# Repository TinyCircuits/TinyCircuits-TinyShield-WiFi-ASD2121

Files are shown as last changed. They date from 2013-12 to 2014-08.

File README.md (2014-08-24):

# TinyCircuits TinyShield WiFi Board
# ASD2121 Rev2

These are the design files for the TinyCircuits ASD2121 Rev 2 PCB.  This is a TinyShield board that has a TI CC3000 WiFi module, local power supply and level shifters to connect between the TinyDuino and the WiFi Module. 

Format is in Cadsoft Eagle format - Eagle version 6.2 was used for the original design.

For more infomation on this, check out the product page at Tiny-Circuits.com:  https://tiny-circuits.com/tiny-shield-wifi.html

#License:

Design by TinyCircuits.
All design files are released under the Creative Commons Attribution Share-Alike 3.0 License, see the following link for details: http://creativecommons.org/licenses/by-sa/3.0

All text above must be included in any redistribution or derived design

This project uses designs and concepts developed as part of the Arduino project and the LilyPad project.  The TinyCircuits design files themselves (schematics, PCB and libraries) are not directly derived from these works' design files and have been created new, however the concepts and basic architecture behind the TinyDuino and TinyLily products are derived and we thank the hard work of the organizations below for their contributions to open-source hardware:
  
Original Arduino Uno Design by Team Arduino

LilyPad Arduino Design by Leah Buechley and Sparkfun Electronics

Please support the open-source hardware community

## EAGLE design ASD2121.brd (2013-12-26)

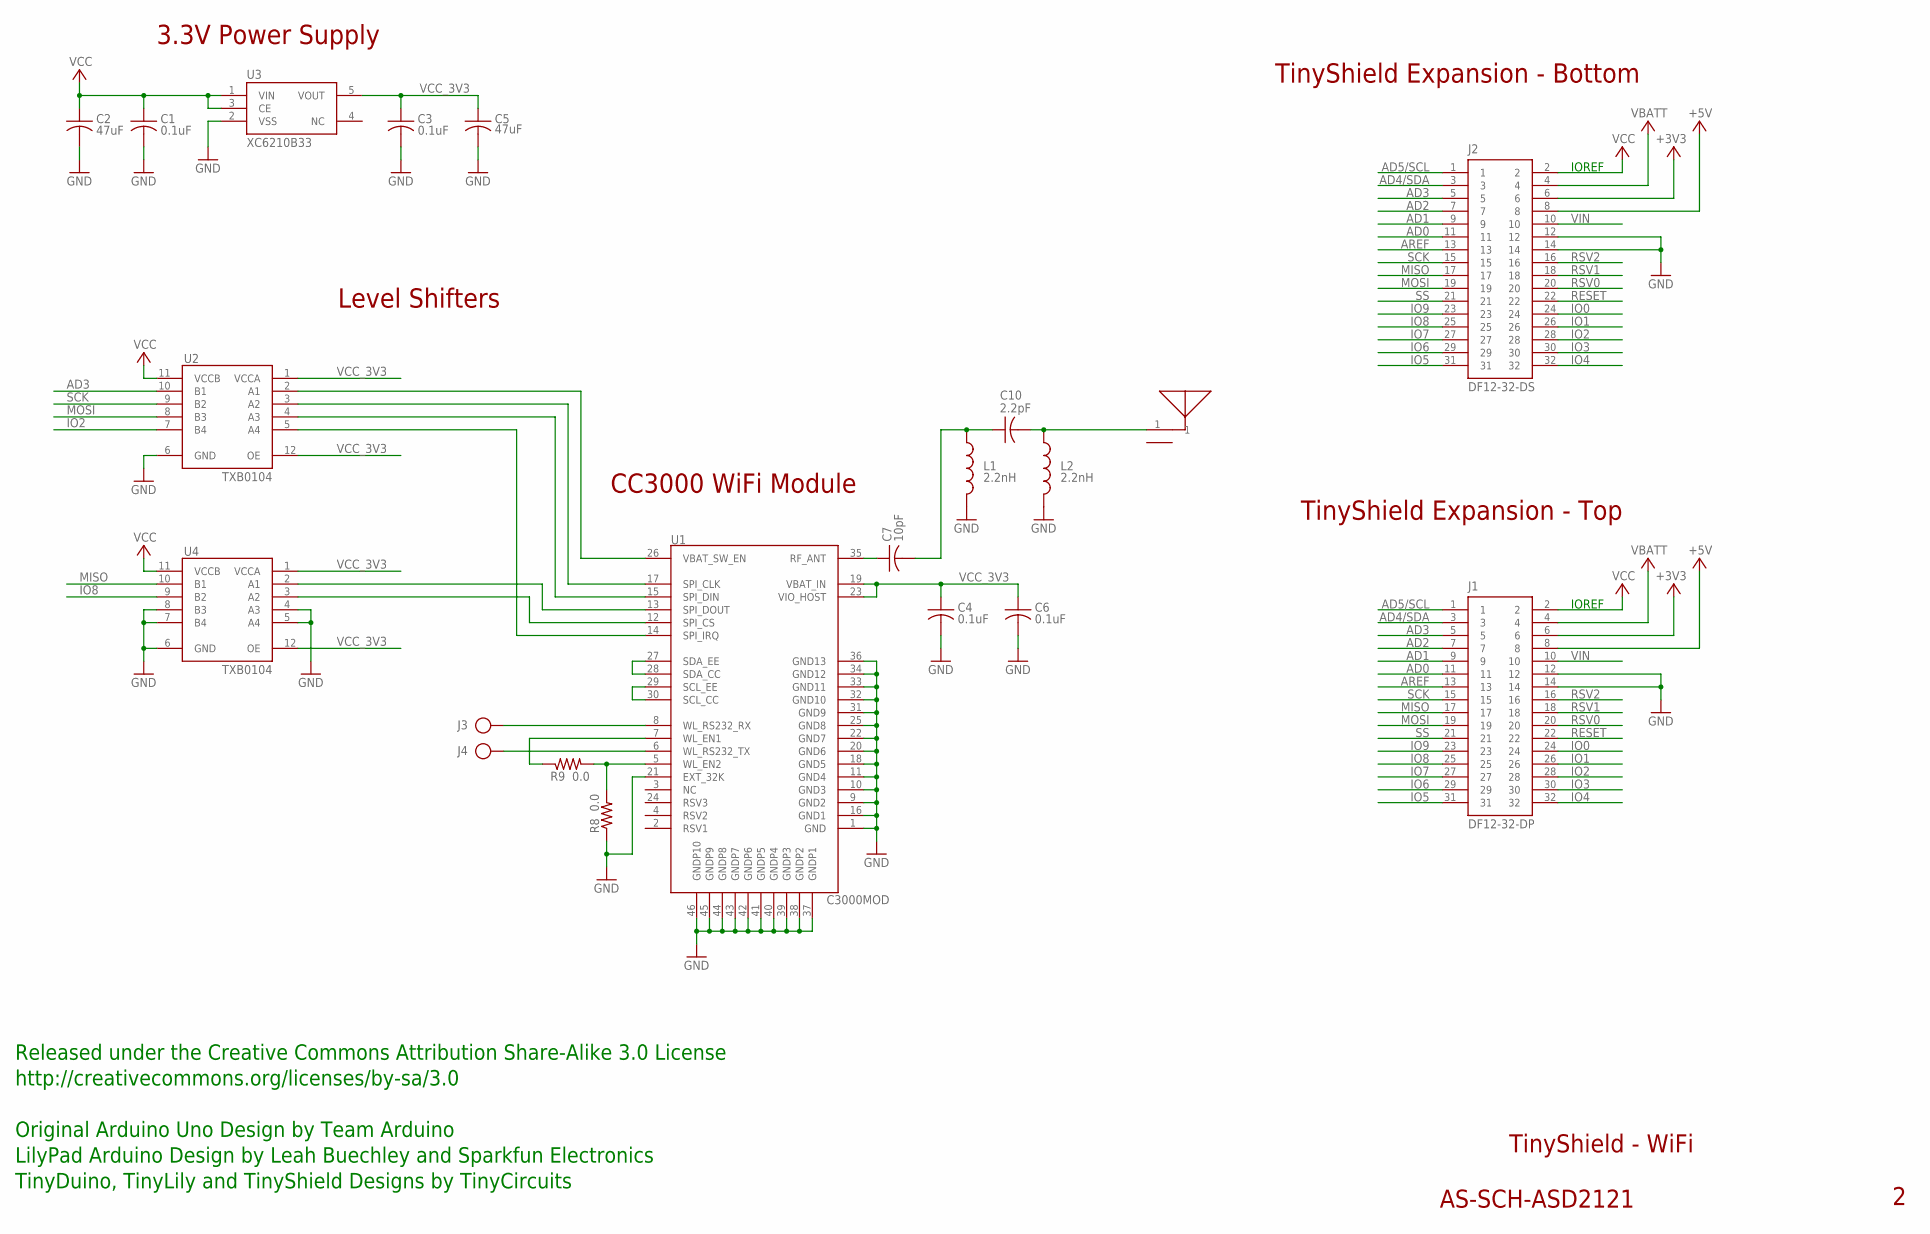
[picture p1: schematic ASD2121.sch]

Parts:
ANT1: AS-ITM-00082; 2G4_ANT
C1, C3, C4, C6: 0.1uF; C0402; PARTNO AS-ITM-00008
C2: 47uF; C1206; PARTNUM AS-ITM-00049
C5: 47uF; C1206
C7: 10pF; C0402; PARTNO AS-ITM-00107
C10: 2.2pF; C0402; PARTNO AS-ITM-00106
J1: DF12-32-DP; PARTNO AS-ITM-00015
J2: DF12-32-DS; PARTNO AS-ITM-00012
J3, J4: PIN_1X.1"SQ_PAD; TEST_POINT
L1, L2: 2.2nH; C0402; PARTNO AS-ITM-00108
R8: 0.0; 0402
R9: 0.0; 0402_SHORT
U1: C3000MOD; CC3000MOD
U2, U4: TXB0104; UQFN-12
U3: XC6210B33; SOT-25

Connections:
+3V3: J1.6, J2.6
+5V: J1.8, J2.8
AD0: J1.11, J2.11
AD1: J1.9, J2.9
AD2: J1.7, J2.7
AD3: J1.5, J2.5, U2.10 (B1)
AD4/SDA: J1.3, J2.3
AD5/SCL: J1.1, J2.1
AREF: J1.13, J2.13
GND: C1.2, C2.2, C3.2, C4.2, C5.2, C6.2, J1.12, J1.14, J2.12, J2.14, L1.2, L2.2, R8.1, U1.1 (GND), U1.9 (GND2), U1.10 (GND3), U1.11 (GND4), U1.16 (GND1), U1.18 (GND5), U1.20 (GND6), U1.21 (EXT_32K), U1.22 (GND7), U1.25 (GND8), U1.31 (GND9), U1.32 (GND10), U1.33 (GND11), U1.34 (GND12), U1.36 (GND13), U1.37 (GNDP1), U1.38 (GNDP2), U1.39 (GNDP3), U1.40 (GNDP4), U1.41 (GNDP5), U1.42 (GNDP6), U1.43 (GNDP7), U1.44 (GNDP8), U1.45 (GNDP9), U1.46 (GNDP10), U2.6 (GND), U3.2 (VSS), U4.4 (A3), U4.5 (A4), U4.6 (GND), U4.7 (B4), U4.8 (B3)
IO0: J1.24, J2.24
IO1: J1.26, J2.26
IO2: J1.28, J2.28, U2.7 (B4)
IO3: J1.30, J2.30
IO4: J1.32, J2.32
IO5: J1.31, J2.31
IO6: J1.29, J2.29
IO7: J1.27, J2.27
IO8: J1.25, J2.25, U4.9 (B2)
IO9: J1.23, J2.23
MISO: J1.17, J2.17, U4.10 (B1)
MOSI: J1.19, J2.19, U2.8 (B3)
unnamed: U1.29 (SCL_EE), U1.30 (SCL_CC)
unnamed: U1.27 (SDA_EE), U1.28 (SDA_CC)
unnamed: U1.14 (SPI_IRQ), U2.5 (A4)
unnamed: U1.12 (SPI_CS), U4.3 (A2)
unnamed: J3.P$1, U1.8 (WL_RS232_RX)
unnamed: U1.13 (SPI_DOUT), U4.2 (A1)
unnamed: U1.15 (SPI_DIN), U2.4 (A3)
unnamed: J4.P$1, U1.6 (WL_RS232_TX)
unnamed: R8.2, R9.2, U1.5 (WL_EN2)
unnamed: R9.1, U1.7 (WL_EN1)
unnamed: U1.17 (SPI_CLK), U2.3 (A2)
unnamed: U1.26 (VBAT_SW_EN), U2.2 (A1)
unnamed: C7.1, U1.35 (RF_ANT)
unnamed: C7.2, C10.1, L1.1
unnamed: ANT1.1, C10.2, L2.1
RESET: J1.22, J2.22
RSV0: J1.20, J2.20
RSV1: J1.18, J2.18
RSV2: J1.16, J2.16
SCK: J1.15, J2.15, U2.9 (B2)
SS: J1.21, J2.21
VBATT: J1.4, J2.4
VCC: C1.1, C2.1, J1.2, J2.2, U2.11 (VCCB), U3.1 (VIN), U3.3 (CE), U4.11 (VCCB)
VCC_3V3: C3.1, C4.1, C5.1, C6.1, U1.19 (VBAT_IN), U1.23 (VIO_HOST), U2.1 (VCCA), U2.12 (OE), U3.5 (VOUT), U4.1 (VCCA), U4.12 (OE)
VIN: J1.10, J2.10

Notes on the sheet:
TinyShield Expansion - Bottom
TinyShield - WiFi
AS-SCH-ASD2121
TinyShield Expansion - Top
IOREF
Released under the Creative Commons Attribution Share-Alike 3.0 License
http://creativecommons.org/licenses/by-sa/3.0
LilyPad Arduino Design by Leah Buechley and Sparkfun Electronics
TinyDuino, TinyLily and TinyShield Designs by TinyCircuits
Original Arduino Uno Design by Team Arduino
3.3V Power Supply
CC3000 WiFi Module
Level Shifters

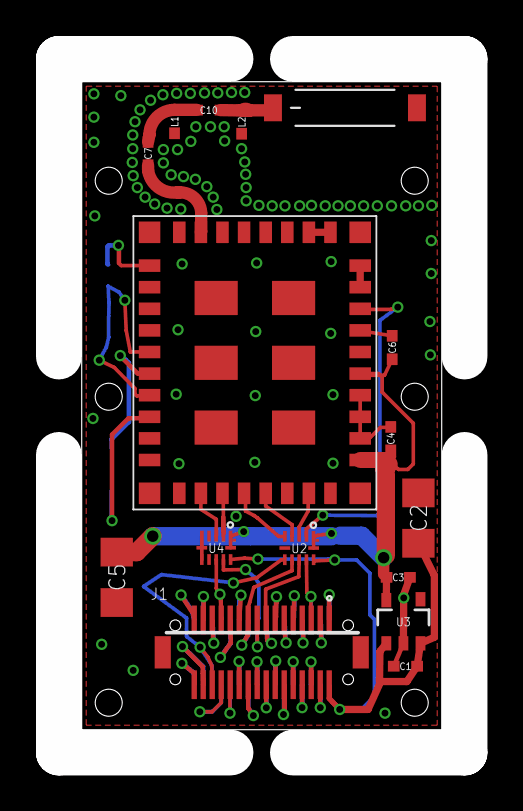
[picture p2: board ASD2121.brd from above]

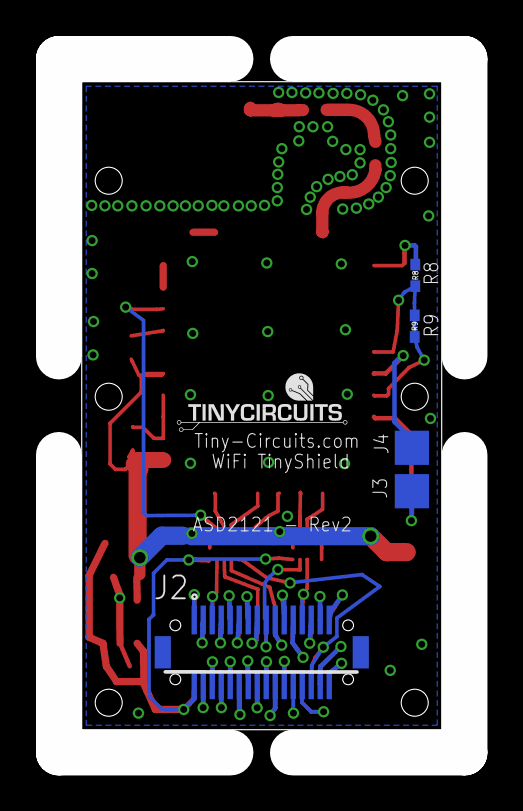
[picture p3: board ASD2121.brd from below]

Board: 2 copper layers, 20.0 x 36.0 mm, 22 parts (5 on the bottom side), 47 nets.

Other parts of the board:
U$1: DOCFIELD-TINYCIRCUITS-PCB
